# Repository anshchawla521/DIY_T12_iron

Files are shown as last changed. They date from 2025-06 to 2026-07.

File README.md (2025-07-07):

# DIY_T12_iron  

This repository conatins all the files for the DIY soldering iron which is compatible with hakko 936 style station and is meant to be used as the replacement PCB for HAKKO 936 style clones. This can support HAKKO T12 irons, HAKKO A1560(hakko 936 station) style irons as well as JBC c245 iron(yet to be checked).  

## Images

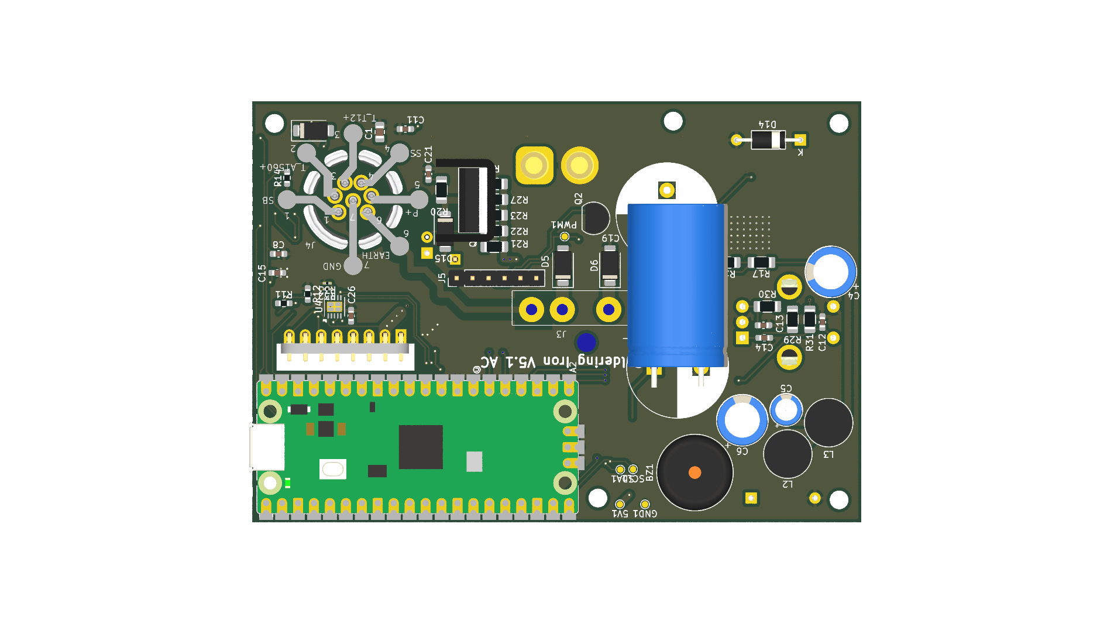
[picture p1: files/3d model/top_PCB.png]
top view
  
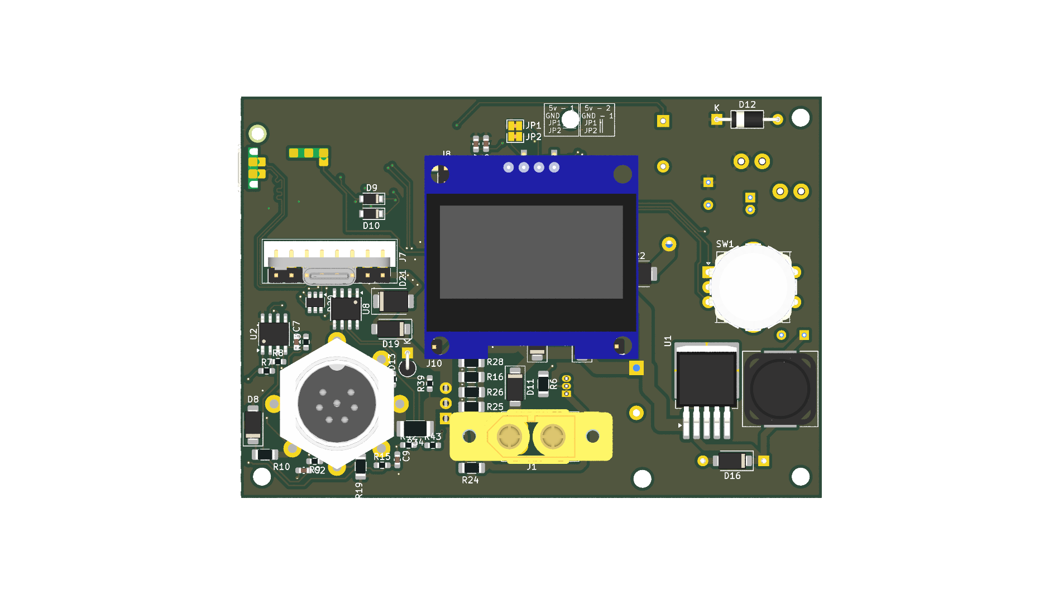
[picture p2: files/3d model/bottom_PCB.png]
Bottom View
  

## Schematic  

Schematic
Front fabrication
Bottom Fabrication  

## Code

The original Code was written by [HomeMade Projects](https://www.youtube.com/watch?v=tIUbGNTiDyI). Later i modified it to work with the provided PCB + support for more types of Iron's  

## What did i Learn ?

I learnt that most of the iron's use a triac and are AC powere or if they are DC work only upto 24V because making mosfets work/switch 60V is very hard

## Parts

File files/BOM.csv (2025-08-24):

Reference | Value | Description | Qty
5V1,GND1,PWM1,SCL1,SDA1,VBUS1 | TestPoint | test point | 6
A1 | Arduino_Nano_v2.x | Arduino Nano v2.x | 1
BZ1 | Buzzer | Buzzer, polarized | 1
C1 | 0.47uf | Polarized capacitor | 1
C2,C7 | 2nf | Unpolarized capacitor | 2
C4,C6 | 220uf | Polarized capacitor | 2
C5 | 4.7uF | Polarized capacitor | 1
C8,C9,C10,C11,C12,C13,C14,C15,C16,C17,C18,C20,C21,C23,C25,C27,C28 | 100nf | Unpolarized capacitor | 17
C19,C24 | 1000uF | Polarized capacitor | 2
C22 | 1nf | Unpolarized capacitor | 1
C26 | 1uF | Unpolarized capacitor | 1
D1,D9,D10,D12 | 5V | Zener diode | 4
D2,D3,D4,D5,D6,D7,D8,D11,D15,D16,D17,D18,D19 | SS310 | 100V 3A Schottky Diode, SMA | 13
D13 | 18V | Zener diode | 1
D14 | 1N5822 | 40V 3A Schottky Barrier Rectifier Diode, DO-201AD | 1
D20 | ESDA6V1-5SC6 | Quintuple bidirectional transil, Suppressor for ESD protection, 6V1 Breakdown, SOT-23-6 | 1
D21 | SMBJ24A | 600W unidirectional Transil Transient Voltage Suppressor, 6.8Vrwm, DO-214AA | 1
D22 | SMBJ45A | 600W unidirectional Transil Transient Voltage Suppressor, 6.8Vrwm, DO-214AA | 1
F1 | Fuse | Fuse 1A 1206 | 1
J1 | DC INPUT | Generic connector, single row, 01x02, script generated | 1
J2 | USB TO SERIAL | Generic connector, single row, 01x04, script generated | 1
J3 | AC input | Generic connector, single row, 01x03, script generated | 1
J4 | output_connector | Generic connector, single row, 01x07, script generated | 1
J5 | mosfet_driver_future_backup | Generic connector, single row, 01x06, script generated | 1
J6 | OLED | Generic connector, single row, 01x04, script generated | 1
J7 | USB C BREAKOUT BOARD | Generic connector, single row, 01x08, script generated | 1
J8,J10,J11 | Conn_01x01_Socket | Generic connector, single row, 01x01, script generated | 3
JP1,JP2 | SolderJumper_2_Bridged | Solder Jumper, 2-pole, closed/bridged | 2
L1 | 33uH | Inductor | 1
L2,L3 | 100uH | Inductor | 2
Q1 | IRF9540N | -23A Id, -100V Vds, 117mOhm Rds, P-Channel HEXFET Power MOSFET, TO-220 | 1
Q2 | BC547 | 0.1A Ic, 45V Vce, Small Signal NPN Transistor, TO-92 | 1
R1,R3,R4,R9,R13,R14,R15,R29,R30,R31,R33,R37 | 10k | Resistor | 12
R2 | 100k | Resistor | 1
R5,R21,R22,R23,R27 | 1.5k | Resistor | 5
R6 | 2k | Resistor | 1
R7 | 220k | Resistor | 1
R8,R11,R12,R18 | 1k | Resistor | 4
R10 | 470 | Resistor | 1
R16,R24,R25,R26,R28 | 3.3k | Resistor | 5
R17 | 3k | Resistor | 1
R19 | 7.5M | Resistor | 1
R20 | 100 | Resistor | 1
R32 | 22.6K | Resistor | 1
R34,R38 | 5.1K | Resistor | 2
R35 | 1M | Resistor | 1
R36 | 50K | Resistor | 1
SW1 | RotaryEncoder_Switch | Rotary encoder, dual channel, incremental quadrate outputs, with switch | 1
U1 | LM2596S-ADJ | Adjustable 3A Step-Down Voltage Regulator, TO-263 | 1
U2 | LM358 | Low-Power, Dual Operational Amplifiers, DIP-8/SOIC-8/TO-99-8 | 1
U3 | ACS712xLCTR-05B | ±5A Bidirectional Hall-Effect Current Sensor, +5.0V supply, 185mV/A, SOIC-8 | 1
U4 | HUSB238 | USB C PD CONTROLER | 1
U5 | PC817 | DC Optocoupler, Vce 35V, CTR 50-300%, DIP-4 | 1
U6 | REF3040 | 4.096V 50-ppm/°C Max, 50-μA, CMOS Voltage Reference, SOT-23-3 | 1

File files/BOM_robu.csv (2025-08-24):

Reference | Value | Description | Qty | QTY AVAILABLE | SKU
5V1,GND1,PWM1,SCL1,SDA1,VBUS1 | TestPoint | test point | 6 | 0
A1 | Arduino_Nano_v2.x | Arduino Nano v2.x | 1 | 1
BZ1 | Buzzer | Buzzer, polarized | 1 | 4
C1 | 0.47uf | Polarized capacitor | 1 | 9 | R139450
C2,C7 | 2nf | Unpolarized capacitor | 2 | 18 | R207408
C4,C6 | 220uf | Polarized capacitor | 2 | 5
C5 | 4.7uF | Polarized capacitor | 1 | 10
C8,C9,C10,C11,C12,C13,C14,C15,C16,C17,C18,C20,C21,C23,C25,C27,C28 | 100nf | Unpolarized capacitor | 17 | 4 | R136803
C19,C24 | 1000uF | Polarized capacitor | 2 | 2
C22 | 1nf | Unpolarized capacitor | 1 | 5 | R137640
C26 | 1uF | Unpolarized capacitor | 1 | 0
D1,D9,D10,D12 | 5V | Zener diode | 4 | 50
D2,D3,D4,D5,D6,D7,D8,D11,D15,D16,D17,D18,D19 | SS310 | 100V 3A Schottky Diode, SMA | 13 | 10 | R193134
D13 | 18V | Zener diode | 1 | 3 | R191175
D14 | 1N5822 | 40V 3A Schottky Barrier Rectifier Diode, DO-201AD | 1 |  | NA
D20 | ESDA6V1-5SC6 | Quintuple bidirectional transil, Suppressor for ESD protection, 6V1 Breakdown, SOT-23-6 | 1
D21 | SMBJ24A | 600W unidirectional Transil Transient Voltage Suppressor, 6.8Vrwm, DO-214AA | 1
D22 | SMBJ45A | 600W unidirectional Transil Transient Voltage Suppressor, 6.8Vrwm, DO-214AA | 1
F1 | Fuse | Fuse | 1
J1 | DC INPUT | Generic connector, single row, 01x02, script generated | 1 | 1 | xt60
J2 | USB TO SERIAL | Generic connector, single row, 01x04, script generated | 1
J3 | AC input | Generic connector, single row, 01x03, script generated | 1
J4 | output_connector | Generic connector, single row, 01x07, script generated | 1
J5 | mosfet_driver_future_backup | Generic connector, single row, 01x06, script generated | 1
J6 | OLED | Generic connector, single row, 01x04, script generated | 1 | 1
J7 | USB C BREAKOUT BOARD | Generic connector, single row, 01x08, script generated | 1 | 1 | R122667
J8,J10,J11 | Conn_01x01_Socket | Generic connector, single row, 01x01, script generated | 3
JP1,JP2 | SolderJumper_2_Bridged | Solder Jumper, 2-pole, closed/bridged | 2
L1 | 33uH | Inductor | 1 | 1
L2,L3 | 100uH | Inductor | 2 | 3
Q1 | IRF9540N | -23A Id, -100V Vds, 117mOhm Rds, P-Channel HEXFET Power MOSFET, TO-220 | 1
Q2 | BC547 | 0.1A Ic, 45V Vce, Small Signal NPN Transistor, TO-92 | 1 | 9
R1,R3,R4,R9,R13,R33 | 10k | Resistor | 6 | 4 | R138649
R2 | 100k | Resistor | 1 | 15 | 574955
R5,R21,R22,R23,R27 | 1.5k | Resistor | 5
R6 | 2k | Resistor | 1 | 16 | 575040
R7 | 220k | Resistor | 1 | 23 | R137569
R8,R11,R12,R18 | 1k | Resistor | 4 | 19 | 574940
R10 | 470 | Resistor | 1 | 18 | 575217
R14,R15 | 4.7k | Resistor | 2 | use 10k
R16,R24,R25,R26,R28 | 3.3k | Resistor | 5
R17 | 3k | Resistor | 1
R19 | 5M | Resistor | 1
R20 | 100 | Resistor | 1
R29,R30,R31 | 5k | Resistor | 3 | DNP
R32 | 22.6K | Resistor | 1
R34,R38 | 5.1K | Resistor | 2
R35 | 1M | Resistor | 1
R36 | 50K | Resistor | 1
R37 | 10K | Resistor | 1 | use 10k
SW1 | RotaryEncoder_Switch | Rotary encoder, dual channel, incremental quadrate outputs, with switch | 1
U1 | LM2596S-ADJ | Adjustable 3A Step-Down Voltage Regulator, TO-263 | 1
U2 | LM358 | Low-Power, Dual Operational Amplifiers, DIP-8/SOIC-8/TO-99-8 | 1 | 2 | 161970
U3 | ACS712xLCTR-05B | ±5A Bidirectional Hall-Effect Current Sensor, +5.0V supply, 185mV/A, SOIC-8 | 1
U4 | HUSB238 | USB C PD CONTROLER | 1
U5 | PC817 | DC Optocoupler, Vce 35V, CTR 50-300%, DIP-4 | 1
U6 | REF3040 | 4.096V 50-ppm/°C Max, 50-μA, CMOS Voltage Reference, SOT-23-3 | 1

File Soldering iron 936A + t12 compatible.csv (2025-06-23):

Reference | Qty | Value | DNP | Exclude from BOM | Exclude from Board | Footprint | Datasheet
A1 | 1 | Arduino_Nano_v2.x |  |  |  | Module:Arduino_Nano | https://www.arduino.cc/en/uploads/Main/ArduinoNanoManual23.pdf
BZ1 | 1 | Buzzer |  |  |  | Buzzer_Beeper:Buzzer_12x9.5RM7.6 | ~
C1 | 1 | 0.47uf |  |  |  | Capacitor_SMD:C_0805_2012Metric_Pad1.18x1.45mm_HandSolder | ~
C2,C7 | 2 | 2nf |  |  |  | Capacitor_SMD:C_0603_1608Metric_Pad1.08x0.95mm_HandSolder | ~
C3,C11 | 2 | 1000uF |  |  |  | Capacitor_THT:CP_Radial_D10.0mm_P5.00mm | ~
C4,C6 | 2 | 220uf |  |  |  | Capacitor_THT:CP_Radial_D8.0mm_P3.80mm | ~
C5 | 1 | 4.7uF |  |  |  | Capacitor_THT:CP_Radial_D5.0mm_P2.00mm | ~
C8,C9,C10,C12,C13,C14 | 6 | 100nf |  |  |  | Capacitor_SMD:C_0603_1608Metric_Pad1.08x0.95mm_HandSolder | ~
D1 | 1 | 5V |  |  |  | Diode_THT:D_DO-41_SOD81_P10.16mm_Horizontal | https://diotec.com/tl_files/diotec/files/pdf/datasheets/zy1
D2 | 1 | 1N5819WS |  |  |  | Diode_SMD:D_SOD-323 | https://datasheet.lcsc.com/lcsc/2204281430_Guangdong-Hottech-1N5819WS_C191023.pdf
D3,D4,D5,D6,D11 | 5 | SS310 |  |  |  | Diode_SMD:D_SMA | https://www.microdiode.com/uploadfiles//PDF/SS32-THRU-SS3200-SMA.pdf
D7,D8,D15 | 3 | 1N5824 |  |  |  | Diode_SMD:D_SOD-323 | https://datasheet.lcsc.com/lcsc/2204281430_Guangdong-Hottech-1N5819WS_C191023.pdf
D9,D10,D12 | 3 | 5V |  |  |  | Diode_THT:D_A-405_P10.16mm_Horizontal | ~
D13 | 1 | 18V |  |  |  | Diode_THT:D_A-405_P10.16mm_Horizontal | ~
D14 | 1 | 1N5822 |  |  |  | Diode_THT:D_A-405_P10.16mm_Horizontal | http://www.vishay.com/docs/88526/1n5820.pdf
J1 | 1 | DC INPUT |  |  |  | Connector_AMASS:AMASS_XT60-F_1x02_P7.20mm_Vertical | ~
J2 | 1 | OLED |  |  |  | Connector_PinHeader_2.54mm:PinHeader_1x04_P2.54mm_Vertical | ~
J3 | 1 | AC input |  |  |  | Library:BY-G4 | ~
J4 | 1 | output_connector |  |  |  | Library:aviaion_connector | ~
J5 | 1 | mosfet_driver_future_backup |  |  |  | Connector_PinHeader_2.54mm:PinHeader_1x06_P2.54mm_Vertical | ~
L1 | 1 | 33uH |  |  |  | Inductor_SMD:L_12x12mm_H6mm | ~
L2,L3 | 2 | 100uH |  |  |  | Inductor_THT:L_Radial_D7.5mm_P3.50mm_Fastron_07P | ~
Q1 | 1 | IRF9540N |  |  |  | Package_TO_SOT_THT:TO-220-3_Vertical | http://www.irf.com/product-info/datasheets/data/irf9540n.pdf
Q2 | 1 | BC547 |  |  |  | Package_TO_SOT_THT:TO-92_Inline | https://www.onsemi.com/pub/Collateral/BC550-D.pdf
R1,R3,R4,R5,R9,R13 | 6 | 10k |  |  |  | Resistor_SMD:R_1206_3216Metric_Pad1.30x1.75mm_HandSolder | ~
R2 | 1 | 100k |  |  |  | Resistor_SMD:R_1206_3216Metric_Pad1.30x1.75mm_HandSolder | ~
R6 | 1 | 2k |  |  |  | Resistor_SMD:R_1206_3216Metric_Pad1.30x1.75mm_HandSolder | ~
R7 | 1 | 220k |  |  |  | Resistor_SMD:R_1206_3216Metric_Pad1.30x1.75mm_HandSolder | ~
R8,R11,R12,R18 | 4 | 1k |  |  |  | Resistor_SMD:R_1206_3216Metric_Pad1.30x1.75mm_HandSolder | ~
R10 | 1 | 470 |  |  |  | Resistor_SMD:R_1206_3216Metric_Pad1.30x1.75mm_HandSolder | ~
R14,R15 | 2 | 4.7k |  |  |  | Resistor_SMD:R_1206_3216Metric_Pad1.30x1.75mm_HandSolder | ~
R16 | 1 | 10K |  |  |  | Resistor_SMD:R_1206_3216Metric_Pad1.30x1.75mm_HandSolder | ~
R17 | 1 | 3k |  |  |  | Resistor_SMD:R_1206_3216Metric_Pad1.30x1.75mm_HandSolder | ~
SW1 | 1 | RotaryEncoder_Switch |  |  |  | Rotary_Encoder:RotaryEncoder_Alps_EC11E-Switch_Vertical_H20mm_CircularMountingHoles | ~
U1 | 1 | LM2596S-ADJ |  |  |  | Package_TO_SOT_SMD:TO-263-5_TabPin3 | http://www.ti.com/lit/ds/symlink/lm2596.pdf
U2 | 1 | LM358 |  |  |  | Package_SO:SOIC-8-1EP_3.9x4.9mm_P1.27mm_EP2.29x3mm_ThermalVias | http://www.ti.com/lit/ds/symlink/lm2904-n.pdf

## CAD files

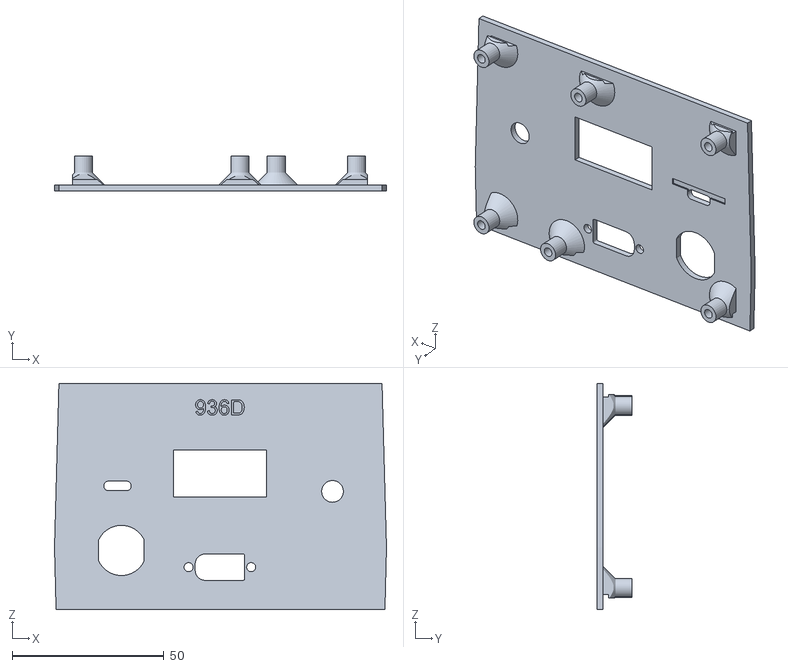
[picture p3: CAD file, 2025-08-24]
files/3d model/front panel.stl
109.3 x 11.5 x 74.6

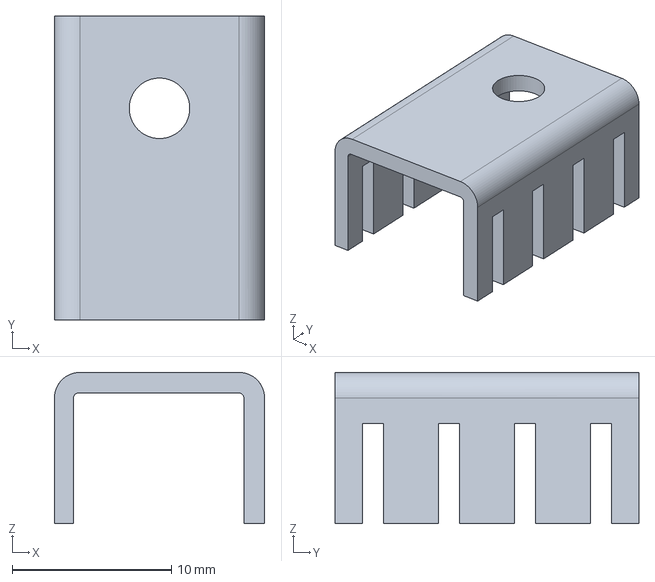
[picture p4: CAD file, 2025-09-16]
wakefield-vette heatsink 274-1AB.stp
13.2 x 19.1 x 9.50 mm

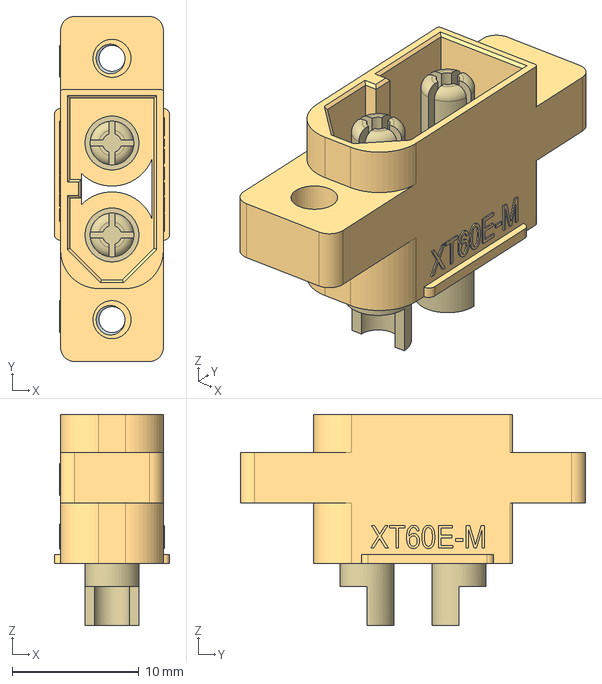
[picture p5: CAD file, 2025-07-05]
XT60E-M_V1.1.stp
9.10 x 27.2 x 16.6 mm

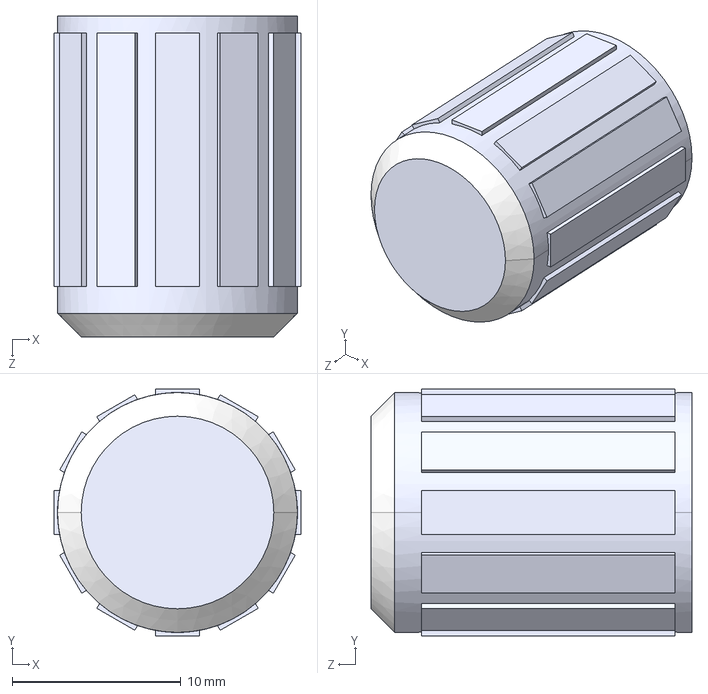
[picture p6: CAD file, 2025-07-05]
RotaryEncKnob.STEP
14.6 x 14.6 x 19.0 mm

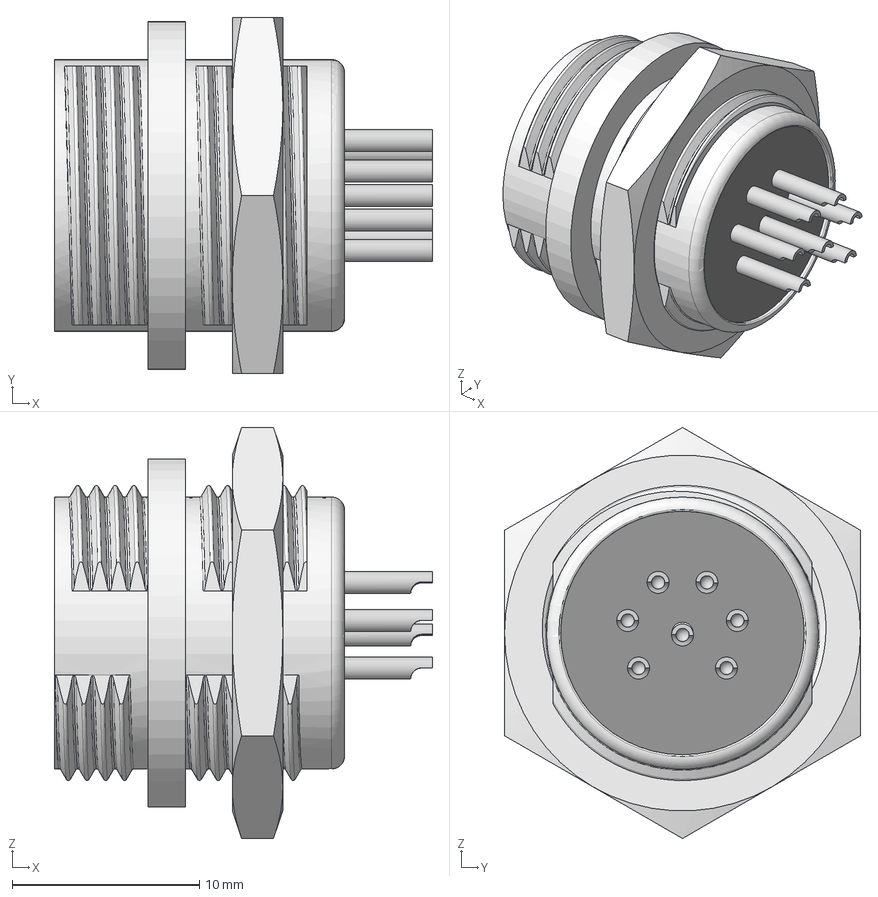
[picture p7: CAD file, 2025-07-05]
GX-16 Connector 7 Pins.step
20.2 x 19.0 x 21.9 mm
Nut
Isolator
Pins

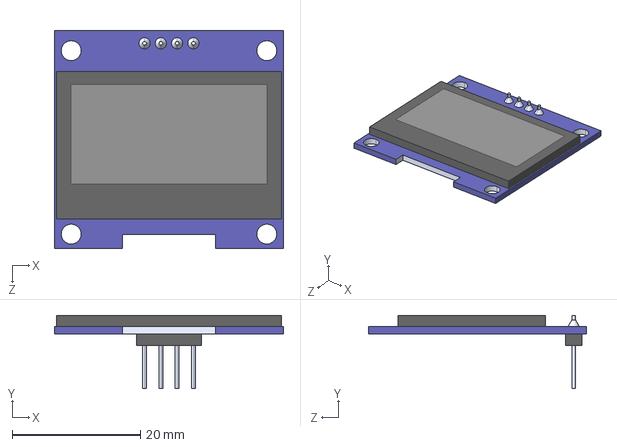
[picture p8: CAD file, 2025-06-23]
Display_OLED_SSD1306_1.3inch (1).STEP
35.7 x 11.4 x 34.0 mm

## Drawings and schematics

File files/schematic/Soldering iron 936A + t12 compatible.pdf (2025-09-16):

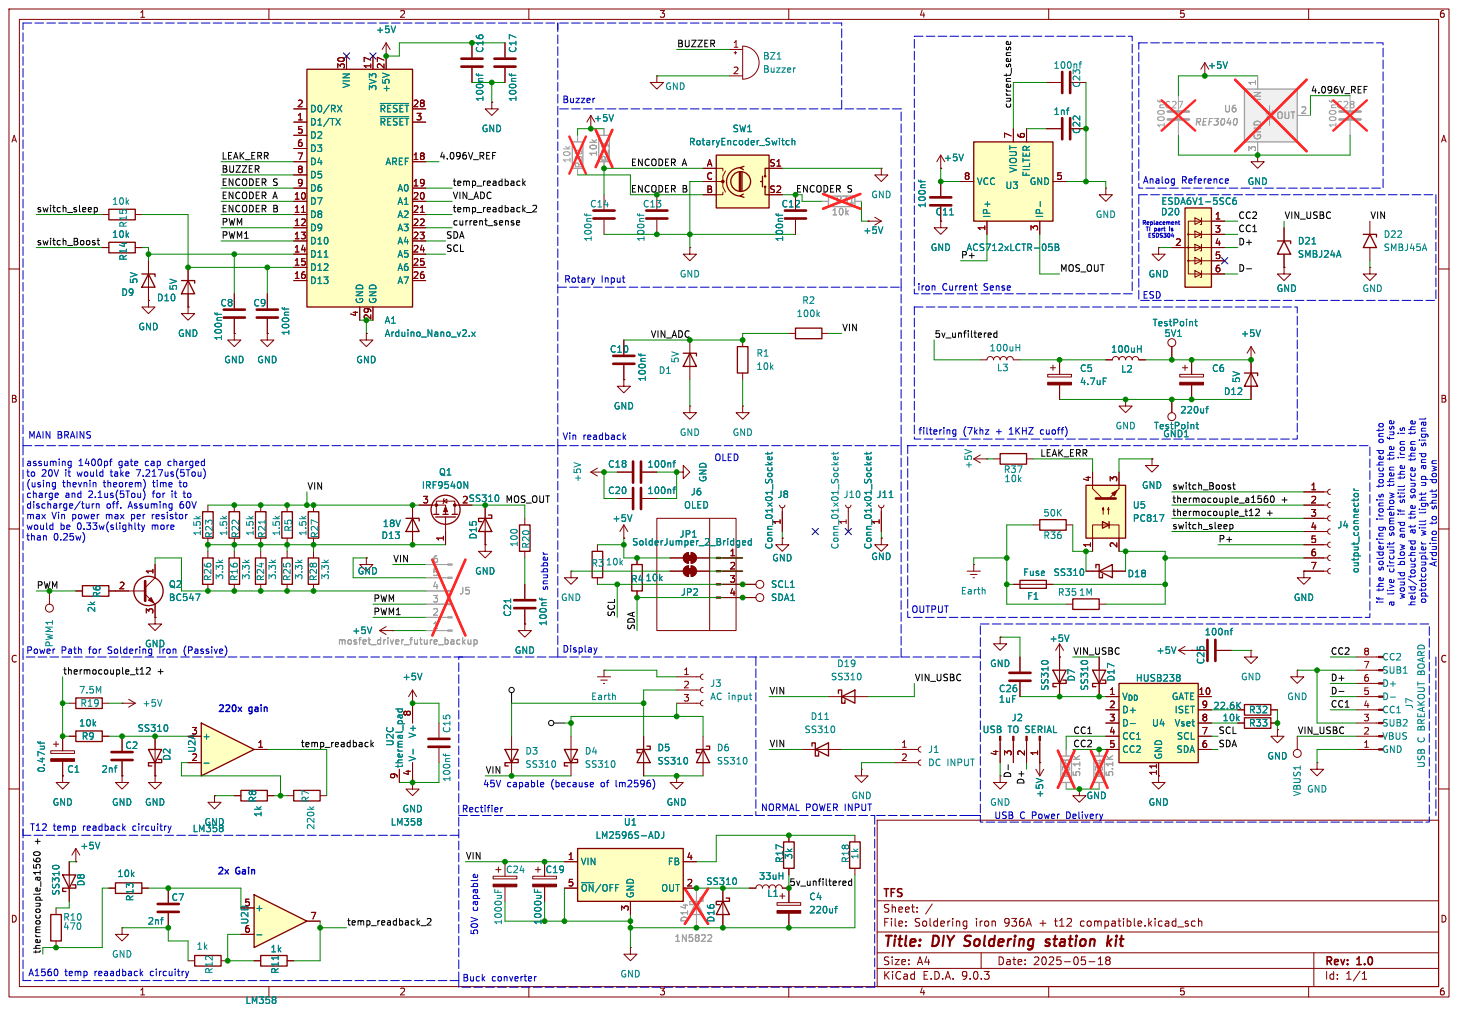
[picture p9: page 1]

Buzzer Display Buck converter

~{RESET} 28 ~{RESET}3 AREF 18 A0 19 A1 20 A2 21 A3 22 A4 23 A5 24 A6 25 A7 26 A1Arduino_Nano_v2.x C16 100nf GND

1 IP- 3 VCC 8 GND 5 VIOUT

Replacement TI part is ESDS304

a live circuit somehow then the fuse would blow and if still the iron is held/touched at the source then the optotcoupler will light up and signal Arduino to shut down

to 20V it would take 7.217us(5Tou)

ISET 9 Vset 8 SCL 7 SDA 6 U4 HUSB238 GND

ISET 9 Vset 8 SCL 7 SDA 6 GND

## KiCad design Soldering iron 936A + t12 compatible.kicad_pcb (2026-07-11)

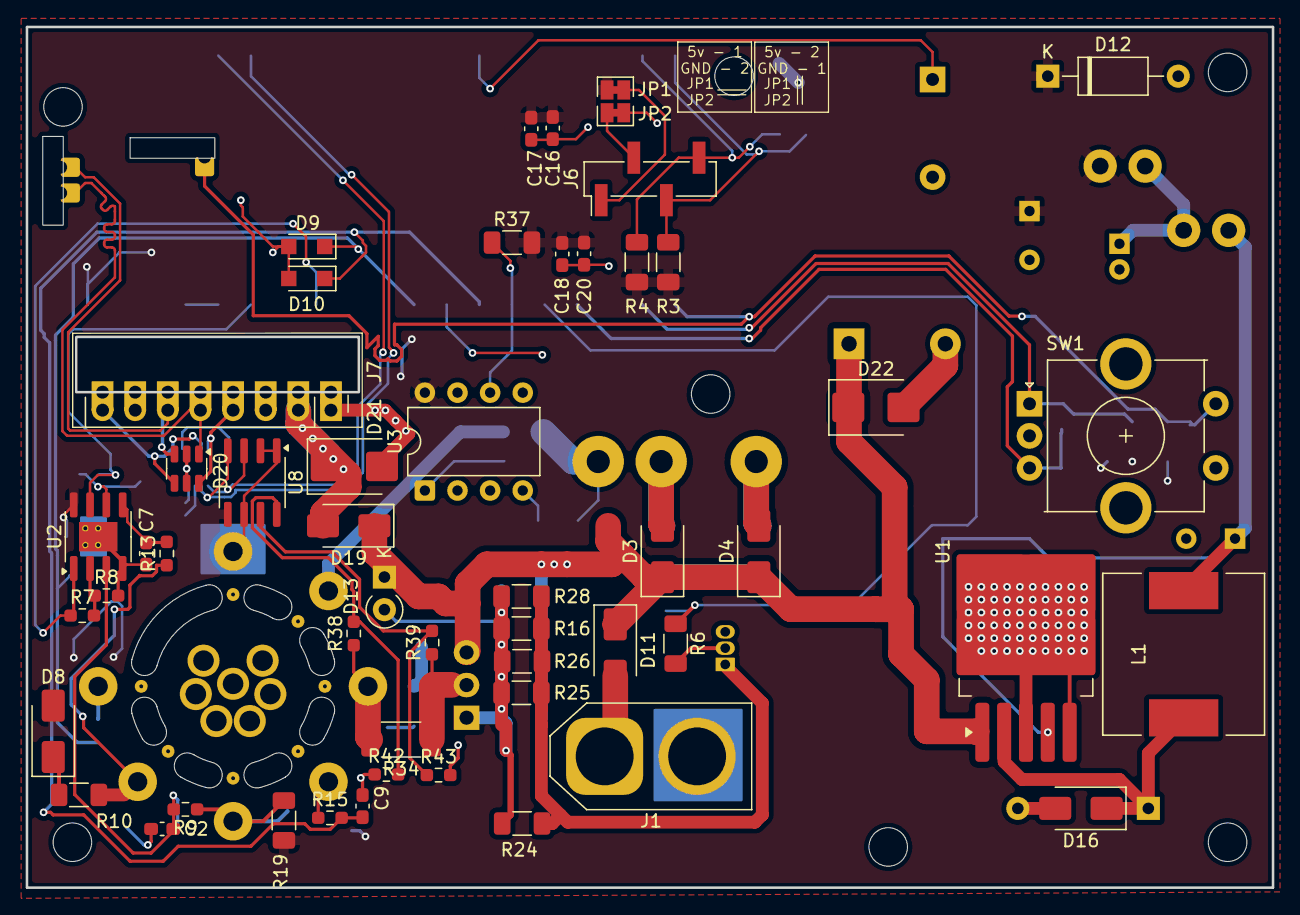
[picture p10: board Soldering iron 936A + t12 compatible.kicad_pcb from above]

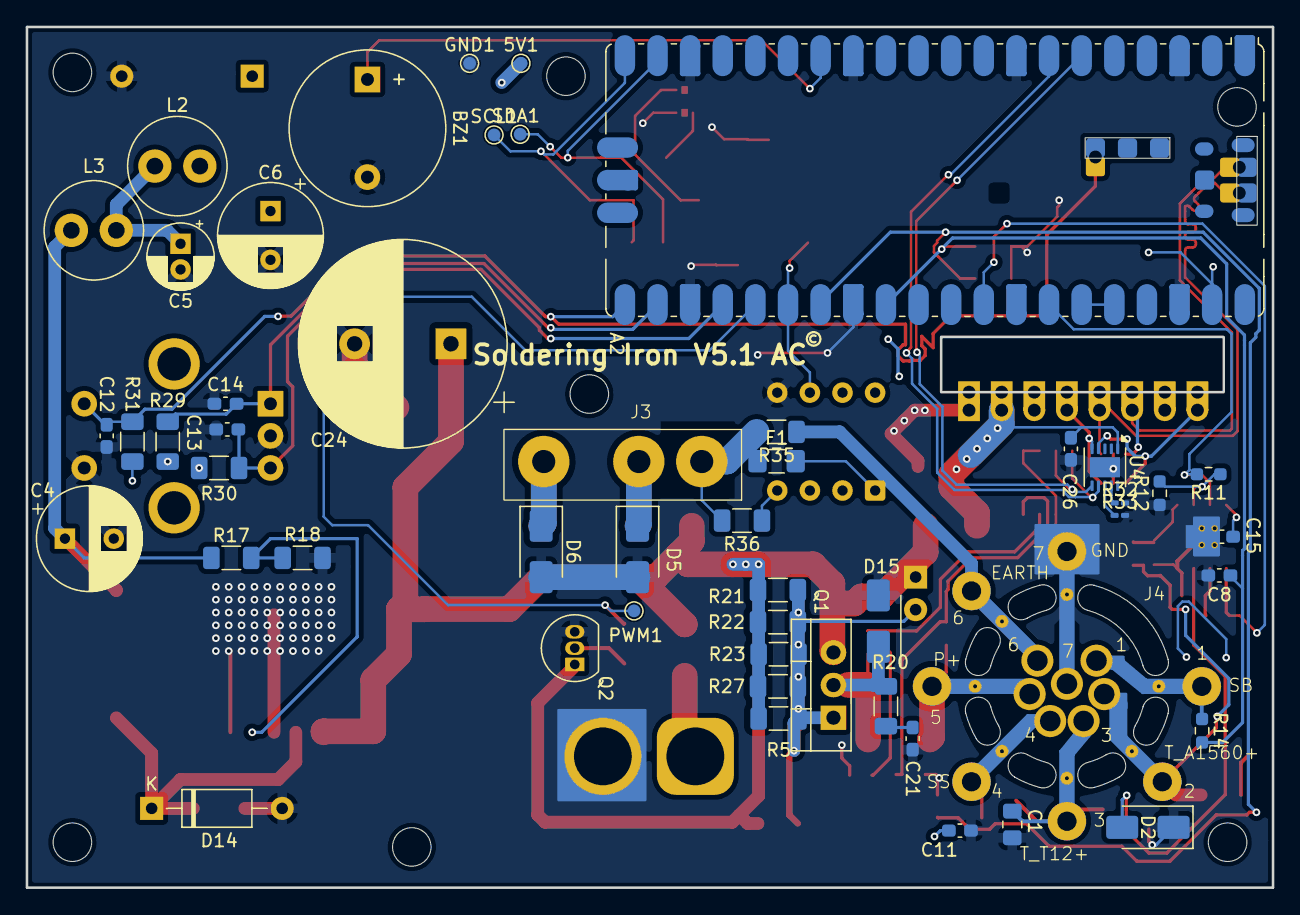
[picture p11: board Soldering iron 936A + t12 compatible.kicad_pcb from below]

Board: 2 copper layers, 97.0 x 67.0 mm, 103 parts (51 on the bottom side), 54 nets.

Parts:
5V1: TestPoint; TestPoint_Pad_D1.0mm
A2: RaspberryPi_Pico; RaspberryPi_Pico_SMD
BZ1: Buzzer; Buzzer_12x9.5RM7.6
C1: 0.47uf; C_0805_2012Metric_Pad1.18x1.45mm_HandSolder
C2, C7: 2nf; C_0603_1608Metric_Pad1.08x0.95mm_HandSolder
C4, C6: 220uf; CP_Radial_D8.0mm_P3.80mm
C5: 4.7uF; CP_Radial_D5.0mm_P2.00mm
C8, C9, C11, C12, C13, C14, C15, C16, C17, C18, C20, C21: 100nf; C_0603_1608Metric_Pad1.08x0.95mm_HandSolder
C24: 1000uF; CP_Radial_D16.0mm_P7.50mm
C26: 1uF; C_0603_1608Metric_Pad1.08x0.95mm_HandSolder
D2, D3, D4, D5, D6, D8, D11, D15, D16, D19: SS310; D_SMA
D9, D10: 3.3; Nexperia_CFP3_SOD-123W
D12: 3.3V; D_A-405_P10.16mm_Horizontal
D13: 18V; D_A-405_P2.54mm_Vertical_KathodeUp
D14: 1N5822; D_A-405_P10.16mm_Horizontal
D20: ESDA6V1-5SC6; SOT-23-6
D21: SMBJ24A; D_SMB
D22: SMBJ45A; D_SMB
F1: Fuse; Fuse_1206_3216Metric_Pad1.42x1.75mm_HandSolder
GND1: TestPoint; TestPoint_Pad_D1.0mm
J1: DC INPUT; AMASS_XT60-F_1x02_P7.20mm_Vertical
J3: AC input; BY-G4
J4: output_connector; aviaion_connector
J6: OLED; PinHeader_1x04_P2.54mm_Vertical_SMD_Pin1Left
J7: USB C BREAKOUT BOARD; PinHeader_1x08_P2.54mm_Vertical
JP1, JP2: SolderJumper_2_Bridged; SolderJumper-2_P1.3mm_Bridged_Pad1.0x1.5mm
L1: 33uH; L_12x12mm_H6mm
L2, L3: 100uH; L_Radial_D7.5mm_P3.50mm_Fastron_07P
PWM1: TestPoint; TestPoint_Pad_D1.0mm
Q1: IRF9540N; TO-220-3_Vertical
Q2: BC547; TO-92_Inline
R3, R4, R29, R30, R31, R37: 10k; R_1206_3216Metric_Pad1.30x1.75mm_HandSolder
R5, R21, R22, R23, R27: 1.5k; R_1206_3216Metric_Pad1.30x1.75mm_HandSolder
R6: 2k; R_1206_3216Metric_Pad1.30x1.75mm_HandSolder
R7: 220k; R_0603_1608Metric_Pad0.98x0.95mm_HandSolder
R8, R11, R12: 1k; R_0603_1608Metric_Pad0.98x0.95mm_HandSolder
R9, R13, R14, R15, R38, R39, R42, R43: 10k; R_0603_1608Metric_Pad0.98x0.95mm_HandSolder
R10: 470; R_1206_3216Metric_Pad1.30x1.75mm_HandSolder
R16, R24, R25, R26, R28: 3.3k; R_1206_3216Metric_Pad1.30x1.75mm_HandSolder
R17: 1.7k; R_1206_3216Metric_Pad1.30x1.75mm_HandSolder
R18: 1k; R_1206_3216Metric_Pad1.30x1.75mm_HandSolder
R19: 7.5M; R_1206_3216Metric_Pad1.30x1.75mm_HandSolder
R20: 100; R_1206_3216Metric_Pad1.30x1.75mm_HandSolder
R32: 22.6K; R_0201_0603Metric_Pad0.64x0.40mm_HandSolder
R33: 10k; R_0201_0603Metric_Pad0.64x0.40mm_HandSolder
R34: 0.1; R_2010_5025Metric_Pad1.40x2.65mm_HandSolder
R35: 1M; R_1206_3216Metric_Pad1.30x1.75mm_HandSolder
R36: 50K; R_1206_3216Metric_Pad1.30x1.75mm_HandSolder
SCL1: TestPoint; TestPoint_Pad_D1.0mm
SDA1: TestPoint; TestPoint_Pad_D1.0mm
SW1: RotaryEncoder_Switch; RotaryEncoder_Alps_EC11E-Switch_Vertical_H20mm_CircularMoun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
U1: LM2596S-ADJ; TO-263-5_TabPin3
U2: LM358; SOIC-8-1EP_3.9x4.9mm_P1.27mm_EP2.29x3mm_ThermalVias
U3: HCPL-3700; DIP-8_W7.62mm
U4: HUSB238; DFN-10-1EP_3x3mm_P0.5mm_EP1.58x2.35mm
U8: INA219AxD; SOIC-8_3.9x4.9mm_P1.27mm

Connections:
+3.3V: 5V1.1, A2.39 (VSYS), C6.1, C11.2, C15.1, C16.1, C17.1, C18.1, C20.1, D8.2 (A), D12.1 (K), JP1.1 (A), L2.2, R3.2, R4.2, R19.2, R29.1, R30.1, R31.2, R37.2, U2.8 (V+), U3.8 (VCC), U8.5 (VS)
+3V3: A2.35 (ADC_VREF), A2.36 (3V3)
/3.3v_unfiltered: C4.1, L1.2, L3.1, R17.2
/BUZZER: A2.14 (GPIO10), BZ1.1 (+)
/CC1: D20.6 (IO5), J7.4 (CC1), U4.5 (CC2)
/CC2: D20.4 (IO3), J7.8 (CC2), U4.4 (CC1)
/D+: A2.TP3 (USB_DP), D20.3 (IO2), J7.6 (D+)
/D-: A2.TP2 (USB_DM), D20.1 (IO1), J7.5 (D-)
/ENCODER A: A2.22 (GPIO17), C14.1, R29.2, SW1.A
/ENCODER B: A2.24 (GPIO18), C13.1, R30.2, SW1.B
/ENCODER S: A2.21 (GPIO16), A2.TP6 (~BOOTSEL), C12.1, R31.1, SW1.S2
/LEAK_ERR: A2.26 (GPIO20), R37.1, U3.6 (VO)
/MOS_OUT: D15.1 (K), Q1.2 (D), R20.1, R34.1, R39.1
/P+: J4.5, R34.2, R38.1
/PWM: A2.25 (GPIO19), PWM1.1, R6.1
/SCL: A2.7 (GPIO5), U4.7 (SCL), U8.4 (SCL)
/SCL1: A2.20 (GPIO15), J6.3 (GND), R3.1, SCL1.1
/SDA: A2.6 (GPIO4), U4.6 (SDA), U8.3 (SDA)
/SDA1: A2.19 (GPIO14), J6.4 (VDD), R4.1, SDA1.1
/VIN: C24.1, D3.1 (K), D4.1 (K), D11.1 (K), D13.1 (K), D19.1 (K), D22.1 (A1), Q1.3 (S), R5.1, R21.1, R22.1, R23.1, R27.1, U1.1 (VIN)
/VIN_USBC: C26.1, D19.2 (A), D21.1 (A1), J7.2 (VBUS), U4.1 (V_{DD})
/switch_Boost: J4.1, R14.1
/switch_Boost_d: A2.29 (GPIO22), C8.1, D9.1 (K), R14.2
/switch_sleep: J4.4, R15.1
/switch_sleep_d: A2.27 (GPIO21), C9.1, D10.1 (K), R15.2
/temp_readback_1: A2.32 (GPIO27_ADC1), R7.1, U2.1
/temp_readback_2: A2.34 (GPIO28_ADC2), R11.2, U2.7
/thermocouple_a1560 +: J4.2, R10.1, R13.1
/thermocouple_t12 +: C1.1, J4.3, R9.1, R19.1
Earth: F1.1, J3.1, R35.2, R36.2
GND: A2.3 (GND), A2.8 (GND), A2.13 (GND), A2.18 (GND), A2.23 (GND), A2.28 (GND), A2.38 (GND), A2.D2 (GND), BZ1.2 (-), C1.2, C2.2, C4.2, C5.2, C6.2, C7.2, C8.2, C9.2, C11.1, C12.2, C13.2, C14.2, C15.2, C16.2, C17.2, C18.2, C20.2, C21.2, C24.2, C26.2, D2.1 (K), D5.2 (A), D6.2 (A), D9.2 (A), D10.2 (A), D12.2 (A), D14.2 (A), D15.2 (A), D16.2 (A), D20.2 (GND), D20.5 (IO4), D21.2 (A2), D22.2 (A2), GND1.1, J1.2, J4.7, J7.1 (GND), JP2.1 (A), Q2.3 (E), R8.2, R12.1, R18.2, R32.2, R33.2, R42.1, R43.2, SW1.C, SW1.S1, U1.3 (GND), U1.5 (~ON/OFF), U2.4 (V-), U2.9 (thermal_pad), U3.5 (GND), U4.11 (GND), U8.1 (A1), U8.2 (A0), U8.6 (GND)
unnamed: C5.1, L2.1, L3.2
unnamed: C21.1, R20.2
unnamed: C2.1, D2.2 (A), R9.2, U2.3 (+)
unnamed: D3.2 (A), D5.1 (K), J3.2
unnamed: D4.2 (A), D6.1 (K), J3.3
unnamed: D8.1 (K), R10.2
unnamed: D11.2 (A), J1.1
unnamed: D13.2 (A), Q1.1 (G), R5.2, R16.2, R21.2, R22.2, R23.2, R24.2, R25.2, R26.2, R27.2, R28.2
unnamed: D14.1 (K), D16.1 (K), L1.1, U1.2 (OUT)
unnamed: F1.2, J4.6, R35.1, U3.1 (AC)
unnamed: J6.2 (SCL), JP2.2 (B)
unnamed: J6.1 (SDA), JP1.2 (B)
unnamed: Q2.2 (B), R6.2
unnamed: Q2.1 (C), R16.1, R24.1, R25.1, R26.1, R28.1
unnamed: R36.1, U3.4 (AC)
unnamed: R17.1, R18.1, U1.4 (FB)
unnamed: R7.2, R8.1, U2.2 (-)
unnamed: C7.1, R13.2, U2.5 (+)
unnamed: R11.1, R12.2, U2.6 (-)
unnamed: R32.1, U4.9 (ISET)
unnamed: R33.1, U4.8 (Vset)
unnamed: R38.2, R42.2, U8.8 (IN+)
unnamed: R39.2, R43.1, U8.7 (IN-)

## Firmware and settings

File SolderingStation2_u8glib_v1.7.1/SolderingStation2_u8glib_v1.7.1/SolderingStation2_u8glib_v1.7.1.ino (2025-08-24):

// SolderingStation2
//
// ATmega328-controlled Soldering Station for Hakko T12 Tips.
//
// This version of the code implements:
// - Temperature measurement of the tip
// - Direct or PID control of the heater
// - Temperature control via rotary encoder
// - Boost mode by short pressing rotary encoder switch
// - Setup menu by long pressing rotary encoder switch
// - Handle movement detection (by checking ball switch)
// - Iron unconnected detection (by idenfying invalid temperature readings)
// - Time driven sleep/power off mode if iron is unused (movement detection)
// - Measurement of input voltage, Vcc and ATmega's internal temperature
// - Information display on OLED
// - Buzzer
// - Calibrating and managing different soldering tips
// - Storing user settings into the EEPROM
// - Tip change detection
//
// Power supply should be in the range of 16V/2A to 24V/3A and well
// stabilized.
//
// For calibration you need a soldering iron tips thermometer. For best results
// wait at least three minutes after switching on the soldering station before
// you start the calibration process.
//
// Controller:  ATmega328p
// Core:        Barebones ATmega (https://github.com/carlosefr/atmega)
// Clockspeed:  16 MHz external
//
// It is recommended not to use a bootloader!
//
// 2019/2020 by Stefan Wagner with great support from John Glavinos
// Project Page: https://easyeda.com/wagiminator
// License: http://creativecommons.org/licenses/by-sa/3.0/



// Libraries
#include <U8glib.h>             // https://github.com/olikraus/u8glib
#include <PID_v1.h>             // https://github.com/mblythe86/C-PID-Library/tree/master/PID_v1
#include <EEPROM.h>             // for storing user settings into EEPROM
#include <avr/sleep.h>          // for sleeping during ADC sampling

// Firmware version
#define VERSION       "v1.7"

// Type of rotary encoder
#define ROTARY_TYPE   1         // 0: 2 increments/step; 1: 4 increments/step (default)

// Pins
#define SENSOR_PIN_T12    A0        // tip temperature sense
#define SENSOR_PIN_A1560    A2        // tip temperature sense
#define VIN_PIN       A1        // input voltage sense
#define BUZZER_PIN     5        // buzzer
#define BUTTON_PIN     6        // rotary encoder switch
#define ROTARY_1_PIN   7        // rotary encoder 1
#define ROTARY_2_PIN   8        // rotary encoder 2
#define CONTROL_PIN    9        // heater MOSFET PWM control
#define SWITCH_PIN    12        // handle vibration switch

// Default temperature control values (recommended soldering temperature: 300-380°C)
#define TEMP_MIN      150       // min selectable temperature
#define TEMP_MAX      400       // max selectable temperature
#define TEMP_DEFAULT  320       // default start setpoint
#define TEMP_SLEEP    150       // temperature in sleep mode
#define TEMP_BOOST     50       // temperature increase in boost mode
#define TEMP_STEP      10       // rotary encoder temp change steps

// Default tip temperature calibration values
#define TEMP200       216       // temperature at ADC = 200
#define TEMP280       308       // temperature at ADC = 280
#define TEMP360       390       // temperature at ADC = 360
#define TEMPCHP       30        // chip temperature while calibration
#define TIPMAX        8         // max number of tips
#define TIPNAMELENGTH 6         // max length of tip names (including termination)
#define TIPNAME       "BC1.5"   // default tip name

// Default timer values (0 = disabled)
#define TIME2SLEEP     5        // time to enter sleep mode in minutes
#define TIME2OFF      15        // time to shut off heater in minutes
#define TIMEOFBOOST   40        // time to stay in boost mode in seconds

// Control values
#define TIME2SETTLE   950       // time in microseconds to allow OpAmp output to settle
#define SMOOTHIE      0.05      // OpAmp output smooth factor (1=no smoothing; 0.05 default)
#define PID_ENABLE    false     // enable PID control
#define BEEP_ENABLE   true      // enable/disable buzzer
#define MAINSCREEN    0         // type of main screen (0: big numbers; 1: more infos)
#define TIP_CHANGEOVER_THRESHOLD 650
#define TIP_A1560_SCALING 1.5

// EEPROM identifier
#define EEPROM_IDENT   0xE76C   // to identify if EEPROM was written by this program

// Define the aggressive and conservative PID tuning parameters
double aggKp = 11, aggKi = 0.5, aggKd = 1;
double consKp = 11, consKi = 3, consKd = 5;

// Default values that can be changed by the user and stored in the EEPROM
uint16_t  DefaultTemp = TEMP_DEFAULT;
uint16_t  SleepTemp   = TEMP_SLEEP;
uint8_t   BoostTemp   = TEMP_BOOST;
uint8_t   time2sleep  = TIME2SLEEP;
uint8_t   time2off    = TIME2OFF;
uint8_t   timeOfBoost = TIMEOFBOOST;
uint8_t   MainScrType = MAINSCREEN;
bool      PIDenable   = PID_ENABLE;
bool      beepEnable  = BEEP_ENABLE;

// Default values for tips
uint16_t  CalTemp[TIPMAX][4] = {TEMP200, TEMP280, TEMP360, TEMPCHP};
char      TipName[TIPMAX][TIPNAMELENGTH] = {TIPNAME};
uint8_t   CurrentTip   = 0;
uint8_t   NumberOfTips = 1;

// Menu items
const char *SetupItems[]       = { "Setup Menu", "Tip Settings", "Temp Settings",
                                   "Timer Settings", "Control Type", "Main Screen",
                                   "Buzzer", "Information", "Return"
                                 };
const char *TipItems[]         = { "Tip:", "Change Tip", "Calibrate Tip",
                                   "Rename Tip", "Delete Tip", "Add new Tip", "Return"
                                 };
const char *TempItems[]        = { "Temp Settings", "Default Temp", "Sleep Temp",
                                   "Boost Temp", "Return"
                                 };
const char *TimerItems[]       = { "Timer Settings", "Sleep Timer", "Off Timer",
                                   "Boost Timer", "Return"
                                 };
const char *ControlTypeItems[] = { "Control Type", "Direct", "PID" };
const char *MainScreenItems[]  = { "Main Screen", "Big Numbers", "More Infos" };
const char *StoreItems[]       = { "Store Settings ?", "No", "Yes" };
const char *SureItems[]        = { "Are you sure ?", "No", "Yes" };
const char *BuzzerItems[]      = { "Buzzer", "Disable", "Enable" };
const char *DefaultTempItems[] = { "Default Temp", "deg C" };
const char *SleepTempItems[]   = { "Sleep Temp", "deg C" };
const char *BoostTempItems[]   = { "Boost Temp", "deg C" };
const char *SleepTimerItems[]  = { "Sleep Timer", "Minutes" };
const char *OffTimerItems[]    = { "Off Timer", "Minutes" };
const char *BoostTimerItems[]  = { "Boost Timer", "Seconds" };
const char *DeleteMessage[]    = { "Warning", "You cannot", "delete your", "last tip!" };
const char *MaxTipMessage[]    = { "Warning", "You reached", "maximum number", "of tips!" };

// Variables for pin change interrupt
volatile uint8_t  a0, b0, c0, d0;
volatile bool     ab0;
volatile int      count, countMin, countMax, countStep;
volatile bool     handleMoved;

// Variables for temperature control
uint16_t  SetTemp, ShowTemp, gap, Step;
double    Input, Output, Setpoint, RawTemp, CurrentTemp, ChipTemp;

// Variables for voltage readings
uint16_t  Vcc, Vin;

// State variables
bool      inSleepMode = false;
bool      inOffMode   = false;
bool      inBoostMode = false;
bool      inCalibMode = false;
bool      isWorky     = true;
bool      beepIfWorky = true;
bool      TipIsPresent = true;

// Timing variables
uint32_t  sleepmillis;
uint32_t  boostmillis;
uint32_t  buttonmillis;
uint8_t   goneMinutes;
uint8_t   goneSeconds;
uint8_t   SensorCounter = 255;

// Specify variable pointers and initial PID tuning parameters
PID ctrl(&Input, &Output, &Setpoint, aggKp, aggKi, aggKd, REVERSE);

// Setup u8g object: uncomment according to the OLED used
//U8GLIB_SSD1306_128X64 u8g(U8G_I2C_OPT_DEV_0|U8G_I2C_OPT_NO_ACK|U8G_I2C_OPT_FAST);
U8GLIB_SH1106_128X64 u8g(U8G_I2C_OPT_FAST | U8G_I2C_OPT_NO_ACK);



void setup() {
  // set the pin modes
  pinMode(SENSOR_PIN_T12,   INPUT);
  pinMode(SENSOR_PIN_A1560,   INPUT);
  pinMode(VIN_PIN,      INPUT);
  pinMode(BUZZER_PIN,   OUTPUT);
  pinMode(CONTROL_PIN,  OUTPUT);
  pinMode(ROTARY_1_PIN, INPUT_PULLUP);
  pinMode(ROTARY_2_PIN, INPUT_PULLUP);
  pinMode(BUTTON_PIN,   INPUT_PULLUP);
  pinMode(SWITCH_PIN,   INPUT_PULLUP);

  analogWrite(CONTROL_PIN, 0);        // this shuts off the heater
  digitalWrite(BUZZER_PIN, LOW);        // must be LOW when buzzer not in use

  // setup ADC
  ADCSRA |= bit (ADPS0) | bit (ADPS1) | bit (ADPS2);  // set ADC prescaler to 128
  ADCSRA |= bit (ADIE);                 // enable ADC interrupt
  interrupts ();                        // enable global interrupts

  // setup pin change interrupt for rotary encoder
  PCMSK0 = bit (PCINT0);                // Configure pin change interrupt on Pin8
  PCICR  = bit (PCIE0);                 // Enable pin change interrupt
  PCIFR  = bit (PCIF0);                 // Clear interrupt flag

  // prepare and start OLED
  if      ( u8g.getMode() == U8G_MODE_R3G3B2 )   u8g.setColorIndex(255);
  else if ( u8g.getMode() == U8G_MODE_GRAY2BIT ) u8g.setColorIndex(3);
  else if ( u8g.getMode() == U8G_MODE_BW )       u8g.setColorIndex(1);
  else if ( u8g.getMode() == U8G_MODE_HICOLOR )  u8g.setHiColorByRGB(255, 255, 255);

  // get default values from EEPROM
  getEEPROM();

  // read supply voltages in mV
  Vcc = getVCC(); Vin = getVIN();

  // read and set current iron temperature
  SetTemp  = DefaultTemp;
  RawTemp  = denoiseAnalog(SENSOR_PIN_T12);
  if (RawTemp > TIP_CHANGEOVER_THRESHOLD)
  {
    // T12 tip not inserted
    RawTemp  = denoiseAnalog(SENSOR_PIN_A1560)/TIP_A1560_SCALING;
  }
  ChipTemp = getChipTemp();
  calculateTemp();

  // turn on heater if iron temperature is well below setpoint
  if ((CurrentTemp + 20) < DefaultTemp) analogWrite(CONTROL_PIN, 255);

  // set PID output range and start the PID
  ctrl.SetOutputLimits(0, 255);
  ctrl.SetMode(AUTOMATIC);

  // set initial rotary encoder values
  a0 = PINB & 1; b0 = PIND >> 7 & 1; ab0 = (a0 == b0);
  setRotary(TEMP_MIN, TEMP_MAX, TEMP_STEP, DefaultTemp);

  // reset sleep timer
  sleepmillis = millis();

  // long beep for setup completion
  beep(); beep();
}


void loop() {
  ROTARYCheck();      // check rotary encoder (temp/boost setting, enter setup menu)
  SLEEPCheck();       // check and activate/deactivate sleep modes
  SENSORCheck();      // reads temperature and vibration switch of the iron
  Thermostat();       // heater control
  MainScreen();       // updates the main page on the OLED
}



// check rotary encoder; set temperature, toggle boost mode, enter setup menu accordingly
void ROTARYCheck() {
  // set working temperature according to rotary encoder value
  SetTemp = getRotary();

  // check rotary encoder switch
  uint8_t c = digitalRead(BUTTON_PIN);
  if ( !c && c0 ) {
    beep();
    buttonmillis = millis();
    while ( (!digitalRead(BUTTON_PIN)) && ((millis() - buttonmillis) < 500) );
    if ((millis() - buttonmillis) >= 500) SetupScreen();
    else {
      inBoostMode = !inBoostMode;
      if (inBoostMode) boostmillis = millis();
      handleMoved = true;
    }
  }
  c0 = c;

  // check timer when in boost mode
  if (inBoostMode && timeOfBoost) {
    goneSeconds = (millis() - boostmillis) / 1000;
    if (goneSeconds >= timeOfBoost) {
      inBoostMode = false;              // stop boost mode
      beep();                           // beep if boost mode is over
      beepIfWorky = true;               // beep again when working temperature is reached
    }
  }
}


// check and activate/deactivate sleep modes
void SLEEPCheck() {
  if (handleMoved) {                    // if handle was moved
    if (inSleepMode) {                  // in sleep or off mode?
      if ((CurrentTemp + 20) < SetTemp) // if temp is well below setpoint
        analogWrite(CONTROL_PIN, 255);    // then start the heater right now
      beep();                           // beep on wake-up
      beepIfWorky = true;               // beep again when working temperature is reached
    }
    handleMoved = false;                // reset handleMoved flag
    inSleepMode = false;                // reset sleep flag
    inOffMode   = false;                // reset off flag
    sleepmillis = millis();             // reset sleep timer
  }

  // check time passed since the handle was moved
  goneMinutes = (millis() - sleepmillis) / 60000;
  if ( (!inSleepMode) && (time2sleep > 0) && (goneMinutes >= time2sleep) ) {
    inSleepMode = true;
    beep();
  }
  if ( (!inOffMode)   && (time2off   > 0) && (goneMinutes >= time2off  ) ) {
    inOffMode   = true;
    beep();
  }
}


// reads temperature, vibration switch and supply voltages
void SENSORCheck() {
  analogWrite(CONTROL_PIN, 0);              // shut off heater in order to measure temperature
  delayMicroseconds(TIME2SETTLE);             // wait for voltage to settle

  double temp = denoiseAnalog(SENSOR_PIN_T12);    // read ADC value for temperature
  if (temp > TIP_CHANGEOVER_THRESHOLD)
  {
    // T12 tip not inserted
    temp  = denoiseAnalog(SENSOR_PIN_A1560)/TIP_A1560_SCALING;
  }
  uint8_t d = digitalRead(SWITCH_PIN);        // check handle vibration switch
  if (d != d0) {
    handleMoved = true;  // set flag if handle was moved
    d0 = d;
  }
  if (! SensorCounter--) Vin = getVIN();      // get Vin every now and then

  analogWrite(CONTROL_PIN, 255 - Output);         // turn on again heater

  RawTemp += (temp - RawTemp) * SMOOTHIE;     // stabilize ADC temperature reading
  calculateTemp();                            // calculate real temperature value

  // stabilize displayed temperature when around setpoint
  if ((ShowTemp != Setpoint) || (abs(ShowTemp - CurrentTemp) > 5)) ShowTemp = CurrentTemp;
  if (abs(ShowTemp - Setpoint) <= 1) ShowTemp = Setpoint;

  // set state variable if temperature is in working range; beep if working temperature was just reached
  gap = abs(SetTemp - CurrentTemp);
  if (gap < 5) {
    if (!isWorky && beepIfWorky) beep();
    isWorky = true;
    beepIfWorky = false;
  }
  else isWorky = false;

  // checks if tip is present or currently inserted
  if (ShowTemp > 500) TipIsPresent = false;   // tip removed ?
  if (!TipIsPresent && (ShowTemp < 500)) {    // new tip inserted ?
    analogWrite(CONTROL_PIN, 0);            // shut off heater
    beep();                                   // beep for info
    TipIsPresent = true;                      // tip is present now
    ChangeTipScreen();                        // show tip selection screen
    updateEEPROM();                           // update setting in EEPROM
    handleMoved = true;                       // reset all timers
    RawTemp  = denoiseAnalog(SENSOR_PIN_T12);     // restart temp smooth algorithm
    if (RawTemp > TIP_CHANGEOVER_THRESHOLD)
    {
      // T12 tip not inserted
      RawTemp  = denoiseAnalog(SENSOR_PIN_A1560)/TIP_A1560_SCALING;
    }
    c0 = LOW;                                 // switch must be released
    setRotary(TEMP_MIN, TEMP_MAX, TEMP_STEP, SetTemp);  // reset rotary encoder
  }
}


// calculates real temperature value according to ADC reading and calibration values
void calculateTemp() {
  if      (RawTemp < 200) CurrentTemp = map (RawTemp,   0, 200,                     21, CalTemp[CurrentTip][0]);
  else if (RawTemp < 280) CurrentTemp = map (RawTemp, 200, 280, CalTemp[CurrentTip][0], CalTemp[CurrentTip][1]);
  else                    CurrentTemp = map (RawTemp, 280, 360, CalTemp[CurrentTip][1], CalTemp[CurrentTip][2]);
}


// controls the heater
void Thermostat() {
  // define Setpoint acoording to current working mode
  if      (inOffMode)   Setpoint = 0;
  else if (inSleepMode) Setpoint = SleepTemp;
  else if (inBoostMode) Setpoint = SetTemp + BoostTemp;
  else                  Setpoint = SetTemp;

  // control the heater (PID or direct)
  gap = abs(Setpoint - CurrentTemp);
  if (PIDenable) {
    Input = CurrentTemp;
    if (gap < 30) ctrl.SetTunings(consKp, consKi, consKd);
    else ctrl.SetTunings(aggKp, aggKi, aggKd);
    ctrl.Compute();
  } else {
    // turn on heater if current temperature is below setpoint
    if ((CurrentTemp + 0.5) < Setpoint) Output = 0; else Output = 255;
  }
  analogWrite(CONTROL_PIN, 255 - Output);   // set heater PWM
}


// creates a short beep on the buzzer
void beep() {
  if (beepEnable) {
    for (uint8_t i = 0; i < 255; i++) {
      digitalWrite(BUZZER_PIN, HIGH);
      delayMicroseconds(125);
      digitalWrite(BUZZER_PIN, LOW);
      delayMicroseconds(125);
    }
  }
}


// sets start values for rotary encoder
void setRotary(int rmin, int rmax, int rstep, int rvalue) {
  countMin  = rmin << ROTARY_TYPE;
  countMax  = rmax << ROTARY_TYPE;
  countStep = rstep;
  count     = rvalue << ROTARY_TYPE;
}


// reads current rotary encoder value
int getRotary() {
  return (count >> ROTARY_TYPE);
}


// reads user settings from EEPROM; if EEPROM values are invalid, write defaults
void getEEPROM() {
  uint16_t identifier = (EEPROM.read(0) << 8) | EEPROM.read(1);
  if (identifier == EEPROM_IDENT) {
    DefaultTemp = (EEPROM.read(2) << 8) | EEPROM.read(3);
    SleepTemp   = (EEPROM.read(4) << 8) | EEPROM.read(5);
    BoostTemp   =  EEPROM.read(6);
    time2sleep  =  EEPROM.read(7);
    time2off    =  EEPROM.read(8);
    timeOfBoost =  EEPROM.read(9);
    MainScrType =  EEPROM.read(10);
    PIDenable   =  EEPROM.read(11);
    beepEnable  =  EEPROM.read(12);
    CurrentTip  =  EEPROM.read(13);
    NumberOfTips = EEPROM.read(14);

    uint8_t i, j;
    uint16_t counter = 15;
    for (i = 0; i < NumberOfTips; i++) {
      for (j = 0; j < TIPNAMELENGTH; j++) {
        TipName[i][j] = EEPROM.read(counter++);
      }
      for (j = 0; j < 4; j++) {
        CalTemp[i][j]  = EEPROM.read(counter++) << 8;
        CalTemp[i][j] |= EEPROM.read(counter++);
      }
    }
  }
  else {
    EEPROM.update(0, EEPROM_IDENT >> 8); EEPROM.update(1, EEPROM_IDENT & 0xFF);
    updateEEPROM();
  }
}


// writes user settings to EEPROM using updade function to minimize write cycles
void updateEEPROM() {
  EEPROM.update( 2, DefaultTemp >> 8);
  EEPROM.update( 3, DefaultTemp & 0xFF);
  EEPROM.update( 4, SleepTemp >> 8);
  EEPROM.update( 5, SleepTemp & 0xFF);
  EEPROM.update( 6, BoostTemp);
  EEPROM.update( 7, time2sleep);
  EEPROM.update( 8, time2off);
  EEPROM.update( 9, timeOfBoost);
  EEPROM.update(10, MainScrType);
  EEPROM.update(11, PIDenable);
  EEPROM.update(12, beepEnable);
  EEPROM.update(13, CurrentTip);
  EEPROM.update(14, NumberOfTips);

  uint8_t i, j;
  uint16_t counter = 15;
  for (i = 0; i < NumberOfTips; i++) {
    for (j = 0; j < TIPNAMELENGTH; j++) EEPROM.update(counter++, TipName[i][j]);
    for (j = 0; j < 4; j++) {
      EEPROM.update(counter++, CalTemp[i][j] >> 8);
      EEPROM.update(counter++, CalTemp[i][j] & 0xFF);
    }
  }
}


// draws the main screen
void MainScreen() {
  u8g.firstPage();
  do {
    // draw setpoint temperature
    u8g.setFont(u8g_font_9x15);
    u8g.setFontPosTop();
    u8g.drawStr( 0, 0,  "SET:");
    u8g.setPrintPos(40, 0);
    u8g.print(Setpoint, 0);

    // draw status of heater
    u8g.setPrintPos(83, 0);
    if (ShowTemp > 500)    u8g.print(F("ERROR"));
    else if (inOffMode)    u8g.print(F("  OFF"));
    else if (inSleepMode)  u8g.print(F("SLEEP"));
    else if (inBoostMode)  u8g.print(F("BOOST"));
    else if (isWorky)      u8g.print(F("WORKY"));
    else if (Output < 180) u8g.print(F(" HEAT"));
    else                   u8g.print(F(" HOLD"));

    // rest depending on main screen type
    if (MainScrType) {
      // draw current tip and input voltage
      float fVin = (float)Vin / 1000;     // convert mv in V
      u8g.setPrintPos( 0, 52); u8g.print(TipName[CurrentTip]);
      u8g.setPrintPos(83, 52); u8g.print(fVin, 1); u8g.print(F("V"));
      // draw pwm percentage
      u8g.setPrintPos(0, 32); u8g.print(map(Output, 255, 0, 0, 100)); u8g.print(F("%"));

      // draw PWM
      u8g.setFont(u8g_font_9x15);
      u8g.setFontPosTop();
      u8g.drawStr( 0, 17,  "PWM");

      // draw current temperature
      u8g.setFont(u8g_font_freedoomr25n);
      u8g.setFontPosTop();
      u8g.setPrintPos(67, 22);
      if (ShowTemp > 500) u8g.print(F("000")); else u8g.print(ShowTemp);
    } else {
      // draw current temperature in big figures
      u8g.setFont(u8g_font_fub42n);
      u8g.setFontPosTop();
      u8g.setPrintPos(15, 20);
      if (ShowTemp > 500) u8g.print(F("000")); else u8g.print(ShowTemp);
    }
  } while (u8g.nextPage());
}


// setup screen
void SetupScreen() {
  analogWrite(CONTROL_PIN, 0);      // shut off heater
  beep();
  uint16_t SaveSetTemp = SetTemp;
  uint8_t selection = 0;
  bool repeat = true;

  while (repeat) {
    selection = MenuScreen(SetupItems, sizeof(SetupItems), selection);
    switch (selection) {
      case 0:   TipScreen(); repeat = false; break;
      case 1:   TempScreen(); break;
      case 2:   TimerScreen(); break;
      case 3:   PIDenable = MenuScreen(ControlTypeItems, sizeof(ControlTypeItems), PIDenable); break;
      case 4:   MainScrType = MenuScreen(MainScreenItems, sizeof(MainScreenItems), MainScrType); break;
      case 5:   beepEnable = MenuScreen(BuzzerItems, sizeof(BuzzerItems), beepEnable); break;
      case 6:   InfoScreen(); break;
      default:  repeat = false; break;
    }
  }
  updateEEPROM();
  handleMoved = true;
  SetTemp = SaveSetTemp;
  setRotary(TEMP_MIN, TEMP_MAX, TEMP_STEP, SetTemp);
}


// tip settings screen
void TipScreen() {
  uint8_t selection = 0;
  bool repeat = true;
  while (repeat) {
    selection = MenuScreen(TipItems, sizeof(TipItems), selection);
    switch (selection) {
      case 0:   ChangeTipScreen();   break;
      case 1:   CalibrationScreen(); break;
      case 2:   InputNameScreen();   break;
      case 3:   DeleteTipScreen();   break;
      case 4:   AddTipScreen();      break;
      default:  repeat = false;      break;
    }
  }
}
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

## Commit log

2025-05-25 second commit
    [Soldering iron 936A + t12 compatible.kicad_pcb, Soldering iron 936A + t12 compatible.kicad_sch]
2025-06-23 PCB arrived , T12 verified , code updating , Fixed mistakes and redid schmatic
    [Display_OLED_SSD1306_1.3inch (1).STEP, Soldering iron 936A + t12 compatible.csv, Soldering iron 936A + t12 compatible.kicad_pcb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]
2025-06-23 added BOM generation + decoupling Cap for other orination of OLED , Fixed PCB orientation in Readme
    [BOM.csv, Soldering iron 936A + t12 compatible.kicad_pcb, Soldering iron 936A + t12 compatible.kicad_sch]
2025-07-01 Updated schematic but have to update layout , foot prints ,add mosfet driver for 31 KHZ driving
    [BOM.csv, Soldering iron 936A + t12 compatible.kicad_sch]
2025-07-05 Schematic finalised -> will do layout next
    [BOM.csv, Soldering iron 936A + t12 compatible.kicad_sch]
2025-07-05 Added all 3d models
    [GX-16 Connector 7 Pins.step, RotaryEncKnob.STEP, Soldering iron 936A + t12 compatible.kicad_pcb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]
2025-07-07 added all 3d model files , almost finalised schematic , rough placment of big components
    [BOM.csv, Soldering iron 936A + t12 compatible.kicad_pcb, Soldering iron 936A + t12 compatible.kicad_sch]
2025-07-12 Finalised schematic , placement
    [BOM.csv, Soldering iron 936A + t12 compatible.kicad_pcb, Soldering iron 936A + t12 compatible.kicad_sch]
2025-07-13 Almost completed layout , checks pending
    [Soldering iron 936A + t12 compatible.kicad_pcb, Soldering iron 936A + t12 compatible.kicad_sch]
2025-07-13 Layout fully complete yet to be reviewed
    [Soldering iron 936A + t12 compatible.kicad_pcb, Soldering iron 936A + t12 compatible.kicad_sch]
2025-07-14 Review 5V and GND planes
    [Soldering iron 936A + t12 compatible.kicad_pcb]
2025-07-14 Checked all errors , fixed whatever was possible only clearance error's exist , now have to check warnings
    [Soldering iron 936A + t12 compatible.kicad_pcb]
2025-07-14 Added , placed refernce , next have to check warnings , silkscreen
    [BOM.csv, Soldering iron 936A + t12 compatible.kicad_pcb, Soldering iron 936A + t12 compatible.kicad_sch]
2025-07-14 Review few of the warnings
    [Soldering iron 936A + t12 compatible.kicad_pcb]
2025-07-15 only warnings are left to see , will now try slots cutting for type c
    [Soldering iron 936A + t12 compatible.kicad_pcb]
2025-07-15 Added cut for the type C board , differential roting pending
    [Soldering iron 936A + t12 compatible.kicad_pcb]
2025-07-15 Length matched the usb data traces
    [Soldering iron 936A + t12 compatible.kicad_pcb]
2025-07-15 widened the slots
    [Soldering iron 936A + t12 compatible.kicad_pcb]
2025-07-15 Centralised the connector and screen
    [Soldering iron 936A + t12 compatible.kicad_pcb]
2025-07-17 added ESD diodes
    [BOM.csv, Soldering iron 936A + t12 compatible.kicad_pcb, Soldering iron 936A + t12 compatible.kicad_sch]
2025-07-19 added esd , oled support headers , oled switchable pinout
    [BOM.csv, Soldering iron 936A + t12 compatible.kicad_pcb, Soldering iron 936A + t12 compatible.kicad_sch]
2025-07-21 sent for FAB , case also designed, lets hope for best
    [Soldering iron 936A + t12 compatible.kicad_pcb, front panel.stl]
2025-08-24 Added castellated edges
    [BOM.csv, BOM_robu.csv, Soldering iron 936A + t12 compatible.kicad_pcb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]
2025-09-16 updated foot print of gx 16 connector
    [Soldering iron 936A + t12 compatible.kicad_pcb, wakefield-vette heatsink 274-1AB.stp]
2026-05-08 final schematic and layout done need to review though , removed uneccesary features
    [Soldering iron 936A + t12 compatible.kicad_pcb]
2026-07-11 re working on layout now
    [Soldering iron 936A + t12 compatible.kicad_pcb, Soldering iron 936A + t12 compatible.kicad_sch]
